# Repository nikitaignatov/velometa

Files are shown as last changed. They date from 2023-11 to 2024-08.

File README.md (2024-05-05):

# velometa

Bike computer for training purpose. The goal is build a device that can present the required information during trainng rides outdoors or indoors.

## Core Sensors

Cores sensors are mainly commercial BLE devices, that provide metrics like HR, Watt, Speed, Cadence and so on. Typically these sensor will provide a measurement once every second.

- [x] Watt
- [x] HR
- [x] Speed
- Cadence

### Sensors

## Experimental Sensors

- [x] GPS
- [x] Static Pressure/Altitude
- [x] Differential Pressure/Pitot tube
- [x] Humidity
- [x] Temperature
- Slope
- Road Vibration
- [x] Airspeed
- [x] Wind Speed
- [x] Position
  - [x] Simple distance tracking (VL53L0X)
  - Advanced multi area distance tracking (VL53L7CX ultrawide FoV)
- Wind Angle
- Tire Pressure
- O2
- CO2

### Sensors 

Sensors will be connected via I2C bus. 
---

#### BME280
[Webpage](https://www.bosch-sensortec.com/products/environmental-sensors/humidity-sensors-bme280/) 
/ 
[Datasheet](https://www.bosch-sensortec.com/media/boschsensortec/downloads/datasheets/bst-bme280-ds002.pdf)

Default address: **0x77**

Used to measure the following parameters

| Parameter | output unit | min | max |
| --- | --- | --- | --- |
| air pressure | Pa | 300 hPa | 1100 hPa |
| air temperature | °C | -40 °C  | 85 °C |
| relative humidity | % | 0 % | 100 % |
---
#### BMP581

---
#### XGZP6897D

[Webpage](https://cfsensor.com/product/i2c-differential-pressure-sensor-xgzp6897d/) 
/ 
[Datasheet](https://cfsensor.com/wp-content/uploads/2022/11/XGZP6897D-Pressure-Sensor-V2.7.pdf)

Default address: **0x6D**

Used to measure the following parameters

| Parameter | output unit | min | max |
| --- | --- | --- | --- |
| differential pressure | Pa | -1000 Pa | 1000 Pa |
| temperature | °C | -30 °C | 120 °C  |

The sensor has built in temperature compensation in the following temperature range: 0..60 °C.

---
#### MPU9250
#### MPU6050
#### BMI160
#### BMI270
#### BMI088
#### ADXL345
#### ADXL355
---
#### VL53L0X
[Webpage](https://www.st.com/en/imaging-and-photonics-solutions/vl53l0x.html) 
/ 
[Datasheet](https://www.st.com/resource/en/datasheet/vl53l0x.pdf)

Default address: **0x52** or **0x29** 

Used to measure the following parameters

| Parameter | output unit | min  | max |
| --- | --- | ---- | --- |
| distance  | mm | 0 mm | 2000 mm |

## Calculated Metric

- [x] Zones
  - [x] HR
  - [x] Power
- ride ftp
- Avg Weighted Power
- Training Load
- W'
- W'bal
- Work above threshold
- HR drift (decoupling)
- CdA

## Sensor connectivity / integration

- BLE for the commercial sensors.

## Data Storage

- Store Timeseries of all connected sensors at all times when device is turned on.
- Activity start/end/pause are stored as markers, so no data is lossed if forgot to start.

## Random Ideas

- Support multi-sensor for 1 metric (2 power meters)
- Control the training bike (adjust resistance ERG)

## Architecture

```mermaid

flowchart TD

subgraph "Peripheral Devices"
  epaper("Epaper Display 4.2inch")
  35screen("WT32-SC01-PLUS")
  7screen("ZX7D00CE01S")
  gps_module("GPS Module")
end

subgraph "Bluetooth LE Sensors"
  bike("Bike Sensors")
  trainer("Tainer Sensors")
  hr_monitor("HR Monitor")
end

subgraph "Microcontroller"
  hspi("HSPI")
  spi("SPI")
  spi---epaper
  hspi---35screen
  hspi---7screen
  ble("BLE")
  ble---bike
  ble---trainer
  ble---hr_monitor  
  uart---gps_module
  uart("UART")
end

subgraph "Core1"
  lvgl("LVGL")
  gfx("GxEPD2")
end

subgraph "Core0"
  sdcard("SDCard")
  gps("GPS")
  speed("Speed")
  power("Power")
  hr("HR")
end

subgraph "Drivers"
  Core1("Core1")
  Core0("Core0")
  hr---ble
  power---ble
  speed---ble
  gps---uart
  lvgl---hspi
  gfx---spi
  sdcard---spi
end

subgraph "Middleware"
  memory("Memory")
  render("Render / UI Components")
  bitmap("Bitmap")
  memory---sdcard
  render---lvgl
  render---gfx
  bitmap---sdcard
end

subgraph "Computation"
  telemetry---memory
  telemetry("Metrics")
  telemetry---gps
  telemetry---speed
  telemetry---hr
  telemetry---power
end

subgraph "Application"
  Computation("Computation")
  screen("Screen")
  map_page("Map")
  page("page")
  screen---render
  screen---map_page
  map_page---bitmap
  map_page---telemetry
  page---telemetry
  screen---page
end

```

## Sensor Data Collection

```mermaid

flowchart LR

subgraph "Peripheral"
  power_sensor1("Assioma")
  power_sensor2("Wahoo Kicker")
  speed_sensor1("Speed Sensor")
  hr_monitor("HR Monitor")
  gps_module("GPS Module")
end

subgraph "Driver"
  ble("BLE")
  gps("GPS")
  hr_monitor---ble  
  speed_sensor1---ble
  power_sensor1---ble
  power_sensor2---ble
  gps_module---gps
end

subgraph "Sensor"
  speed("Speed")
  power("Power")
  hr("HR")
  time("Time")
  elevation("Elevation")
  location("Location")
  ble---hr
  ble---power
  ble---speed
  gps---speed
  gps---elevation
  gps---time
  gps---location
end

subgraph "Computation"
  f("Filter")
  m("Metrics")
  telemetry("Raw Measurements")
  telemetry---f
  f---m
  time---telemetry
  location---telemetry
  elevation---telemetry
  speed---telemetry
  hr---telemetry
  power---telemetry
end

```

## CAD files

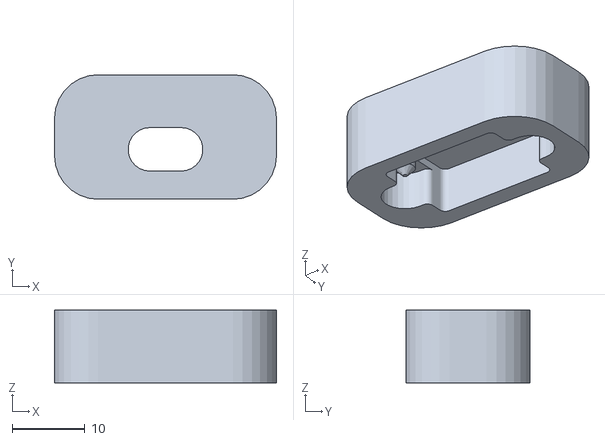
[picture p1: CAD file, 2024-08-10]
3d/wt32sc01_plus_case-Body.stl
30.6 x 17.2 x 10.0

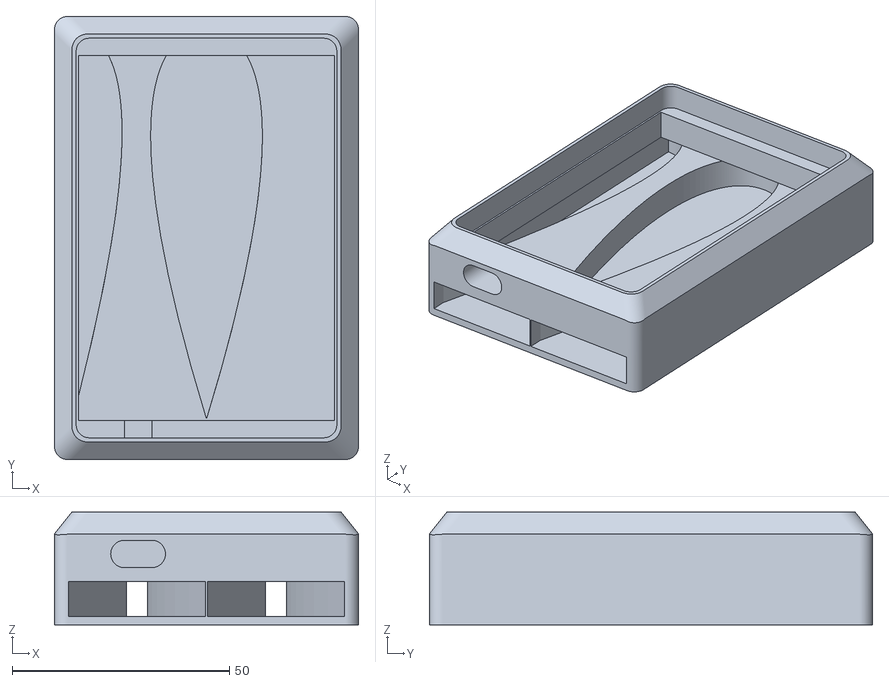
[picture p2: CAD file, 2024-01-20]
3d/wt32sc01_plus_case-enclosure-venturiscreen_mount_venturi.stl
70.0 x 102.0 x 26.0

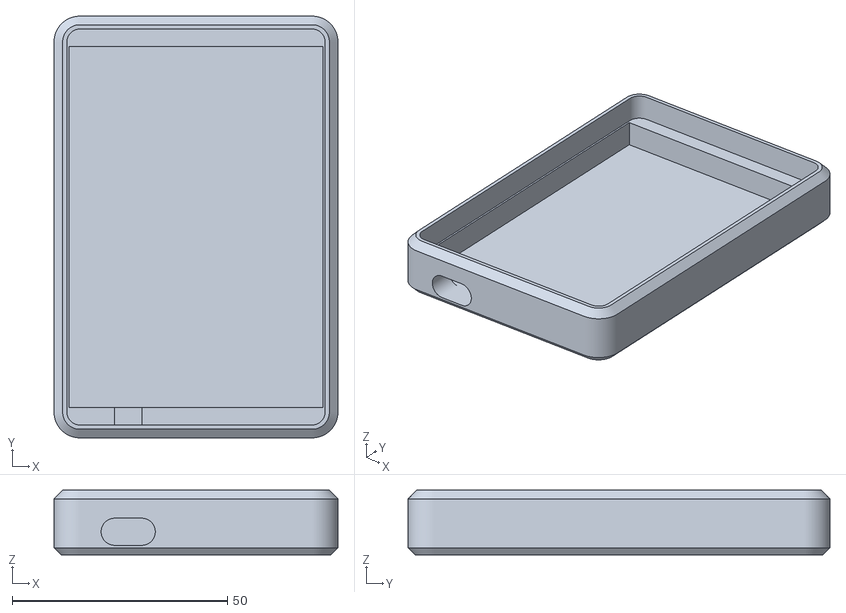
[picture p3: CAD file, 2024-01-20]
3d/wt32sc01_plus_case-screen_mount_basic_2.1.stl
66.0 x 98.0 x 15.0

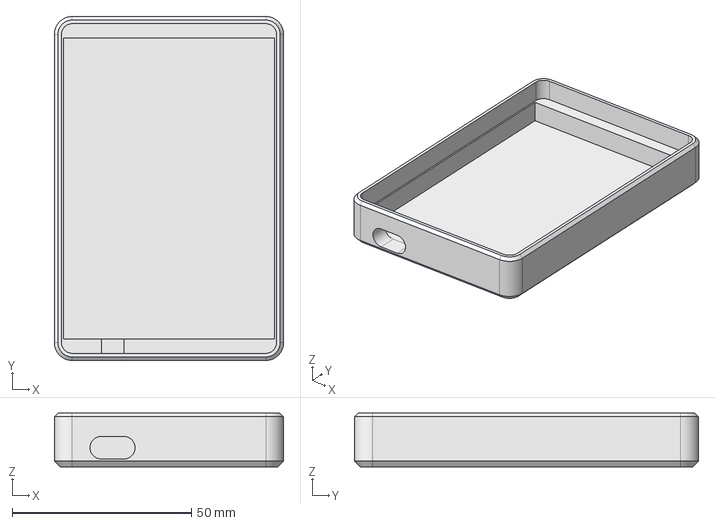
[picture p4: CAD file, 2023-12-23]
3d/wt32sc01_plus_case.FCStd
64.0 x 96.0 x 15.0 mm

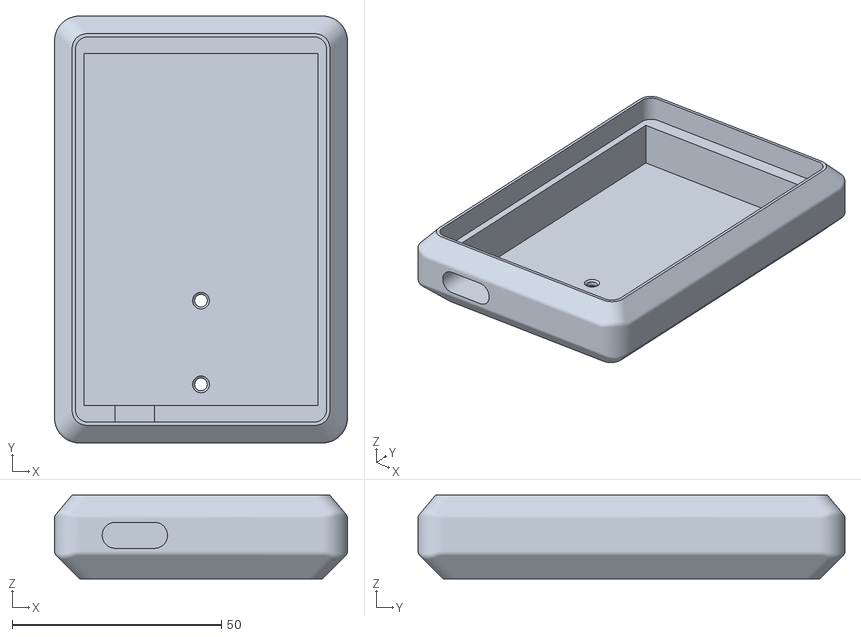
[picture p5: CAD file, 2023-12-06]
3d/wt32sc01_plus_case-enclosurescreen_mount_basic.stl
70.0 x 102.0 x 20.0

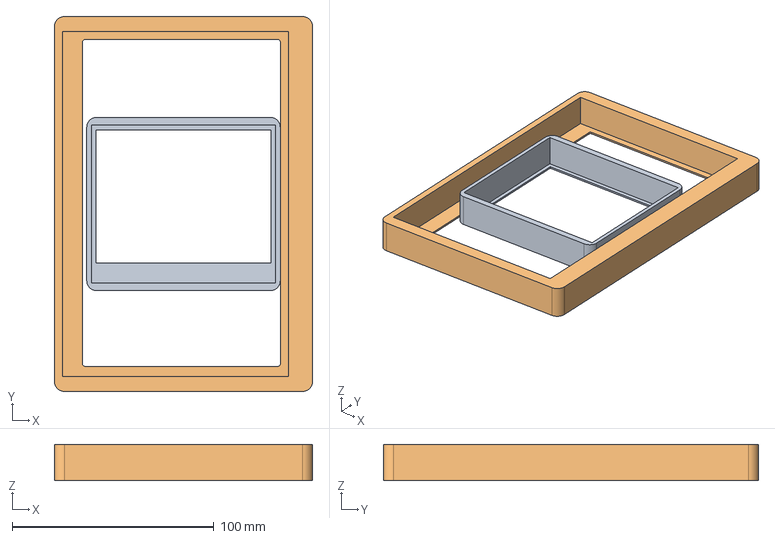
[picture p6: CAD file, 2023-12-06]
3d/case.FCStd
128.0 x 186.0 x 18.0 mm
screen_panel
screen_panel_7_5

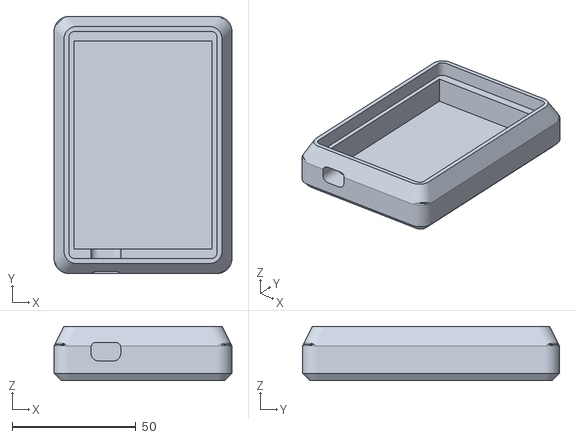
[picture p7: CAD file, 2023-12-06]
3d/wt32sc01_plus_case-enclosurescreen_mount_3.stl
72.0 x 104.0 x 22.0

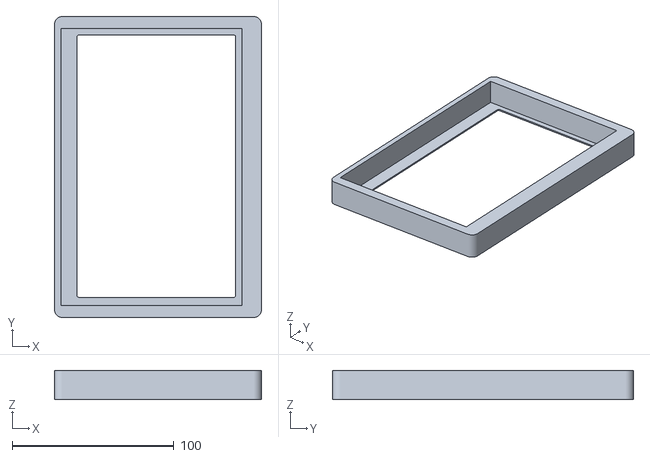
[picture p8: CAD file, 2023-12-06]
3d/case-screen_panel_7_5.stl
128.0 x 186.0 x 18.0

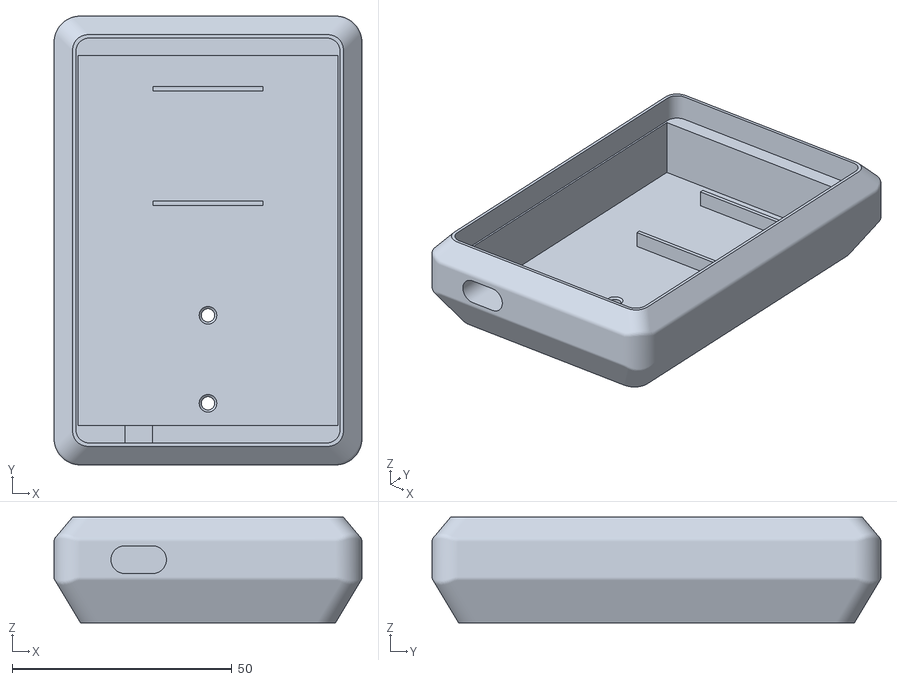
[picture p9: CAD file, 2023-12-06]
3d/wt32sc01_plus_case-enclosurescreen_mount_basic_v1.stl
70.0 x 102.0 x 24.0

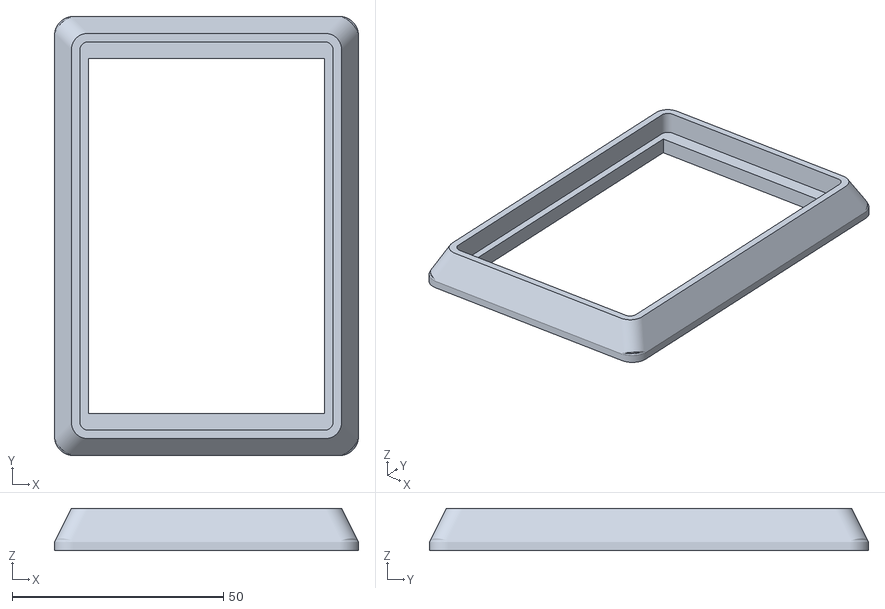
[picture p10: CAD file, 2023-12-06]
3d/wt32sc01_plus_case-enclosurescreen_mount.stl
72.0 x 104.0 x 10.0

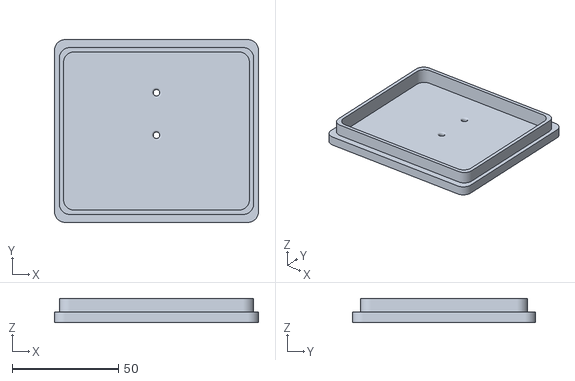
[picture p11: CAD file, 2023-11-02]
3d/case-420Screeen_screen_panel001.stl
96.0 x 86.0 x 11.5

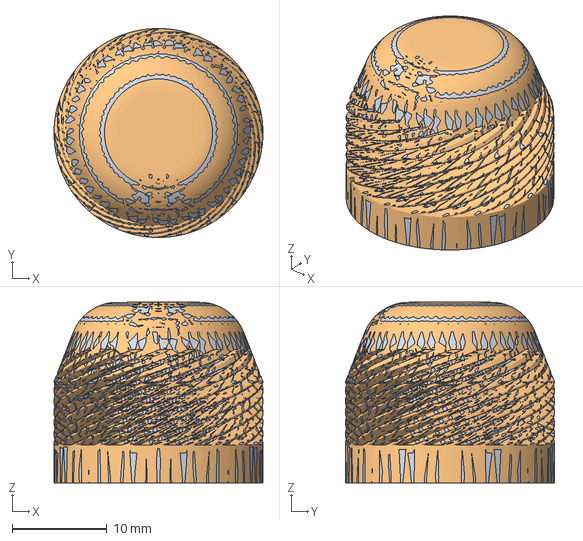
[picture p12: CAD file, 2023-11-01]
3d/controller.FCStd
22.0 x 22.0 x 19.0 mm
Body001 (Meshed)

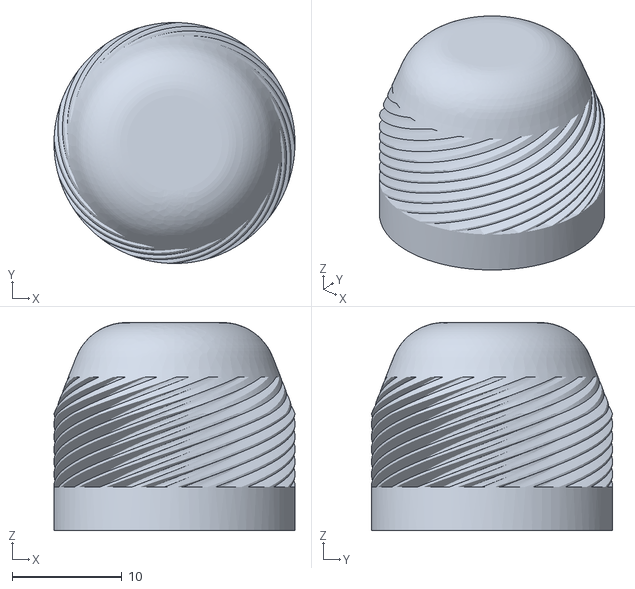
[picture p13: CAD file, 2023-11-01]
3d/controller-knob-mesh.stl
22.0 x 22.0 x 19.0

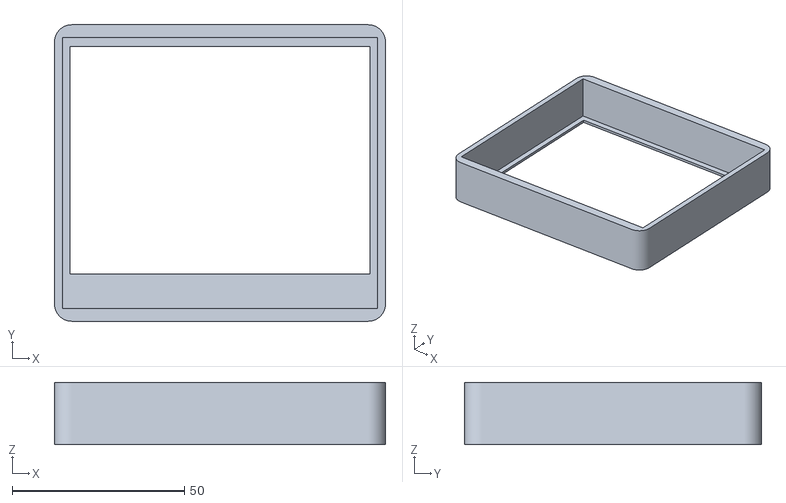
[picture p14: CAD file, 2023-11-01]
3d/case-420Screeenscreen_case.stl
96.0 x 86.0 x 18.0

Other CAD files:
3d/wt32sc01_plus_case-screen_mount_basic_2.stl
3d/wt32sc01_plus_case-enclosurescreen_mount_2.stl
3d/controller-knob.stl
3d/case-Lid.stl
3d/case-Body.stl

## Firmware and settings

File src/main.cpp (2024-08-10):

#include "esp_log.h"
#include "config.hpp"
#include <fmt/core.h>
#include <fmt/ranges.h>
#include <Arduino.h>
#include "types.hpp"
#include "ble.hpp"
#include "gps.hpp"
#include "mock_data.hpp"
#include "activity.hpp"
#include <ff.h>
#include "sensor_reader.hpp"

RTC_DATA_ATTR int start_count = 0;

uint16_t map_frequency = 1000;
SemaphoreHandle_t vh_display_semaphore;
SemaphoreHandle_t vm_sdcard_semaphor;

FATFS *fatfs;
#include "wt32sc01plus.hpp"

TaskHandle_t ble_task;
TaskHandle_t sensor_reader;
TaskHandle_t display_task;
TaskHandle_t activity_task;
TaskHandle_t gps_task;

std::vector<sensor_definition_t> ble_sensors;
QueueHandle_t vh_raw_measurement_queue;
QueueHandle_t vh_metrics_queue;
QueueHandle_t vh_gps_csv_queue;
QueueHandle_t vh_gps_queue;
QueueHandle_t vm_csv_queue;

EventGroupHandle_t sensor_status_bits;

static const char *TAG = "main.cpp";

void setup()
{
    Serial.begin(115200);
    delay(5000);
    Serial.println("Velometa");
    sensor_status_bits = xEventGroupCreate();

    vh_display_semaphore = xSemaphoreCreateMutex();
    if (vh_display_semaphore == NULL)
    {
        ESP_LOGE(TAG, "Failed to create display semaphore");
    }

    vh_gps_queue = xQueueCreate(1000, sizeof(gps_data_t));
    if (vh_gps_queue == NULL)
    {
        ESP_LOGE(TAG, "Failed to create vh_gps_queue");
    }

    vm_csv_queue = xQueueCreate(200, sizeof(raw_measurement_msg_t));
    if (vm_csv_queue == NULL)
    {
        ESP_LOGE(TAG, "Failed to create vm_csv_queue");
    }

    vh_gps_csv_queue = xQueueCreate(400, sizeof(gps_data_t));
    if (vh_gps_csv_queue == NULL)
    {
        ESP_LOGE(TAG, "Failed to create vh_gps_csv_queue");
    }

    vm_sdcard_semaphor = xSemaphoreCreateMutex();
    vh_raw_measurement_queue = xQueueCreate(200, sizeof(raw_measurement_msg_t));

    if (psramInit())
    {
        ESP_LOGW(TAG, "\nThe PSRAM is correctly initialized");
        ESP_LOGW(TAG, "PSRAM Size available (bytes): %d", ESP.getFreePsram());
    }
    else
    {
        ESP_LOGE(TAG, "\nPSRAM does not work");
    }

    fatfs = fs_mount_sd_card();
    Serial.print(fatfs->fsize);
    Serial.println(" init_sdspi");

    xTaskCreatePinnedToCore(
        display_task_code, /* Function to implement the task */
        "display_task",    /* Name of the task */
        32 * 1024,         /* Stack size in words */
        NULL,              /* Task input parameter */
        0,                 /* Priority of the task */
        &display_task,     /* Task handle. */
        1);                /* Core where the task should run */
        
    // PSRAM Initialisation
    if (psramInit())
    {
        Serial.println("\nThe PSRAM is correctly initialized");
        Serial.println((String) "PSRAM Size available (bytes): " + ESP.getFreePsram());
    }
    else
    {
        Serial.println("\nPSRAM does not work");
    }

    ble_sensors.push_back((sensor_definition_t){
        .device_name = DEVICE_NAME_HR,
        .metric = metric_type_t::HR_BPM,
        .service_id = BLEUUID("0000180d-0000-1000-8000-00805f9b34fb"),
        .characteristic_id = {{measurement_t::heartrate, BLEUUID((uint16_t)0x2A37)}},
        .address = missing_address,
        .client = nullptr,
        .parse_data = ble_parse_hr_data,
        .enabled = false,
        .address_type = esp_ble_addr_type_t::BLE_ADDR_TYPE_RANDOM,
        .has_notification = true,
    });

    ble_sensors.push_back((sensor_definition_t){
        .device_name = DEVICE_NAME_HR2,
        .metric = metric_type_t::HR_BPM,
        .service_id = BLEUUID("0000180d-0000-1000-8000-00805f9b34fb"),
        .characteristic_id = {{measurement_t::heartrate, BLEUUID((uint16_t)0x2A37)}},
        .address = missing_address,
        .client = nullptr,
        .parse_data = ble_parse_hr_data,
        .enabled = false,
        .address_type = esp_ble_addr_type_t::BLE_ADDR_TYPE_RANDOM,
        .has_notification = true,
    });

    ble_sensors.push_back((sensor_definition_t){
        .device_name = DEVICE_NAME_POWER,
        .metric = metric_type_t::POWER_WATT,
        .service_id = BLEUUID("00001818-0000-1000-8000-00805f9b34fb"),
        .characteristic_id = {{measurement_t::power, BLEUUID((uint16_t)0x2A63)}},
        .address = missing_address,
        .client = nullptr,
        .parse_data = ble_parse_power_watt_data,
        .enabled = false,
        .address_type = esp_ble_addr_type_t::BLE_ADDR_TYPE_RANDOM,
        .has_notification = true,
    });

    // xTaskCreatePinnedToCore(
    //     mock_task_code, /* Function to implement the task */
    //     "mock_task",    /* Name of the task */
    //     8 * 1024,       /* Stack size in words */
    //     NULL,           /* Task input parameter */
    //     0,              /* Priority of the task */
    //     NULL,           /* Task handle. */
    //     0);             /* Core where the task should run */

    xTaskCreatePinnedToCore(
        write_task_code, /* Function to implement the task */
        "write_task",    /* Name of the task */
        8 * 1024,        /* Stack size in words */
        NULL,            /* Task input parameter */
        0,               /* Priority of the task */
        NULL,            /* Task handle. */
        0);              /* Core where the task should run */

    xTaskCreatePinnedToCore(
        ble_task_code,   /* Function to implement the task */
        "ble_task_code", /* Name of the task */
        16 * 1024,       /* Stack size in words */
        NULL,            /* Task input parameter */
        0,               /* Priority of the task */
        &ble_task,       /* Task handle. */
        0);              /* Core where the task should run */

    xTaskCreatePinnedToCore(
        sensor_reader_task_code, /* Function to implement the task */
        "sensor_reader",         /* Name of the task */
        4 * 1024,                /* Stack size in words */
        NULL,                    /* Task input parameter */
        0,                       /* Priority of the task */
        &sensor_reader,          /* Task handle. */
        0);                      /* Core where the task should run */

    xTaskCreatePinnedToCore(
        activity_task_code,   /* Function to implement the task */
        "activity_task_code", /* Name of the task */
        24 * 1024,            /* Stack size in words */
        NULL,                 /* Task input parameter */
        0,                    /* Priority of the task */
        &activity_task,       /* Task handle. */
        0);                   /* Core where the task should run */

#ifdef FEATURE_GPS_ENABLED
    xTaskCreatePinnedToCore(
        gps_task_code,   /* Function to implement the task */
        "gps_task_code", /* Name of the task */
        4 * 1024,        /* Stack size in words */
        NULL,            /* Task input parameter */
        0,               /* Priority of the task */
        &gps_task,       /* Task handle. */
        0);              /* Core where the task should run */

    xTaskCreatePinnedToCore(
        gps_process_task_code,   /* Function to implement the task */
        "gps_process_task_code", /* Name of the task */
        4 * 1024,                /* Stack size in words */
        NULL,                    /* Task input parameter */
        0,                       /* Priority of the task */
        NULL,                    /* Task handle. */
        0);                      /* Core where the task should run */
#endif

    vTaskDelete(NULL);
}

void loop()
{
}

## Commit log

2023-10-28 driver deps
2023-10-29 removed holes for the buttons
    [case-Body.stl]
2023-10-30 scaling of the chart
    [case-Lid.stl, case.FCStd]
2023-10-30 power zone calc if based on ftp
2023-11-01 change to 420 display
    [case-420Screeenscreen_case.stl, case.FCStd, controller-knob-mesh.stl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]
2023-11-02 case and gui for the 4.2in screen
    [case-420Screeen_screen_panel001.stl, case.FCStd]
2023-11-05 reuse ble code across sensors
2023-11-14 cleanup sensor code
2023-11-17 display min,max,avg for the hr and power chart
2023-11-18 ble drivers
2023-11-18 move sensor into application
2023-11-20 added queue for the ble driver
2023-11-25 new color panel for the computer
    [wt32sc01_plus_case-enclosurescreen_mount.stl, wt32sc01_plus_case.FCStd]
2023-11-25 case design
    [case-screen_panel_7_5.stl, case.FCStd, wt32sc01_plus_case-enclosurescreen_mount_2.stl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]
2023-11-25 correct size for the usb adapter
    [wt32sc01_plus_case-enclosurescreen_mount_basic_v1.stl, wt32sc01_plus_case.FCStd]
2023-11-26 lvgl example with sensor data
2023-11-26 update the rendering
    [wt32sc01_plus_case-enclosurescreen_mount_basic_v1.stl, wt32sc01_plus_case.FCStd]
2023-11-30 sdcard moved into drivers
2023-12-09 data mock for sensor and gps
2023-12-10 added fonts and layout for the hr and power widtget
2023-12-17 remove the arduino dependecy for mock data
2023-12-19 added hr and power chart to dashboard
2023-12-21 new case
    [wt32sc01_plus_case-screen_mount_basic_2.stl]
2023-12-21 stronger sizewalls for new case
    [wt32sc01_plus_case-screen_mount_basic_2.stl, wt32sc01_plus_case.FCStd]
2023-12-23 hr zone histogram
    [wt32sc01_plus_case.FCStd]
2024-01-20 venturi case
    [wt32sc01_plus_case-enclosure-venturiscreen_mount_venturi.stl, wt32sc01_plus_case-screen_mount_basic_2.1.stl]
2024-01-20 modified case
2024-02-03 delay setup when device failes to initialze
    [main.cpp]
2024-02-04 velometa_airspeed ble sensor
2024-03-26 enclosure with tubes to external sensor
2024-03-28 changed the cda screen to show gps speed, power, wind speed and both pressure channels
2024-04-13 added gyro and roll,pitch,yaw
2024-04-17 changed the formatting for gyro
2024-05-05 change the gps to rx pin, reduce the sampling position traacking
2024-05-05 migrated the sensors from airspeed repo: - diff pressure XGZP6897D , - environmental BME280 - position VL53L0X
2024-05-05 streamline sensor reading task
2024-05-26 atmospheric pressure to elevation
2024-07-14 env sensor
2024-07-22 added wind yaw experiment
2024-08-10 added vl53l5cs, the performance outdoors was very noisy, needs some more work with enclosure to shade the sunlight
2024-08-10 3d models
    [wt32sc01_plus_case-Body.stl]
